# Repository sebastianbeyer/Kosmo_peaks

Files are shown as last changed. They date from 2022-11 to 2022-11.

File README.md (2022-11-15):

# Summit is a KOSMO adaption of [Matias Levy's bluepill version](https://github.com/matias-levy/peaks) of [Mutable instrument's Peaks](https://mutable-instruments.net/modules/peaks/)

> **Warning**
> You need the 128k flash version of the bluepill board which might be difficult to obtain. I was lucky with [this](https://www.amazon.com/Teyleten-Robot-Development-STM32F103C8T6-Learning/dp/B08THXZ6XK) item, someone on the LMNC forum was able to get a 128k [here on aliexpress](https://www.aliexpress.us/item/3256801435312142.html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), but there is no guarantee!

## Gerbers
Can be found in the [latest release](https://github.com/sebastianbeyer/Kosmo_peaks/releases/latest)

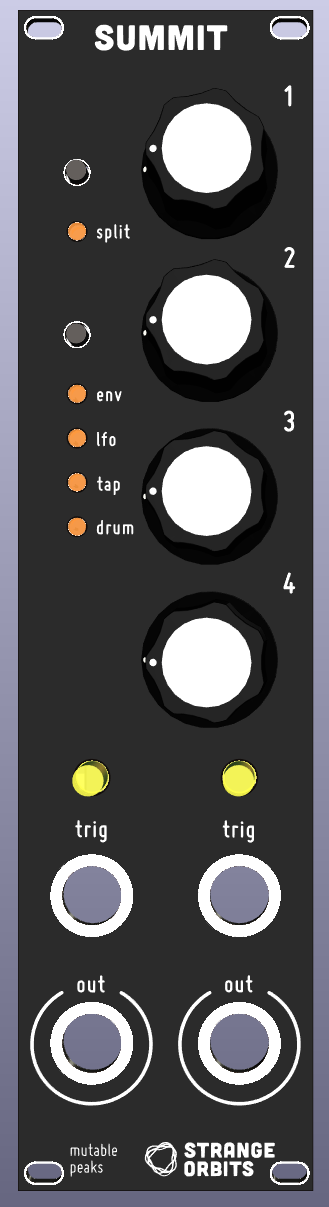
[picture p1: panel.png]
Render of the Panel


## Firmwares
There's the option to flash one of two firmwares that where ported. The original Mutable Instruments one is in the firmware/peaks directory. The [Mutated Mutables Dead Man's Catch](https://github.com/timchurches/Mutated-Mutables/tree/master/peaks) is in the firmware/peaks2. The later adds a lot of functionality to the module, although the UI becomes a bit confusing. <br>
Compiled binaries and HEX files are provided for both under firmware/build.

## Changes
* Added a driver for the PWM DAC running at **14 bit depth, 48Khz sampling rate.** (File in firmware/peaks/drivers/pwm_dac.h)
* Activated the clock for the TIM4 in firmware/peaks/drivers/system.cc
* **Bypassed the bootloader:** This was done as to simplify the code, it does not interfere with the calibration functionality of the module.
* Redesigned the output portion of the hardware to accommodate to the PWM levels.

## Flashing and development
To make it easier I have left binaries and .HEX files in firmware/build, this can be flashed directly to the bluepill using [STM32CubeProgrammer](https://www.st.com/en/development-tools/stm32cubeprog.html). <br>
Another option is to install the [mutable-dev-environment](https://github.com/pichenettes/mutable-dev-environment) and replace the peaks folder with the one inside /firmware, then executing

    make -f peaks/makefile upload_serial

We use this command because the bootloader is bypassed.

## Thanks
I want to thank Emilie Gillet for open-sourcing her work which is a constant inspiration for many musicians and makers, and encourage everyone interested in this project to checkout the [Mutable instrument's Forum](https://forum.mutable-instruments.net/) in which Emilie is a very active member.

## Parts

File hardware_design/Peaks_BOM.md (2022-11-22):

# Peaks.kicad_sch BOM

Tue 22 Nov 2022 12:02:50 CET

Generated from schematic by Eeschema 6.0.8-f2edbf62ab~116~ubuntu22.04.1

**Component Count:** 69

| Refs | Qty | Component | Description | Vendor | SKU |
| ----- | --- | ---- | --- | ---- | ---- |
| C1, C4 | 2 | 150pf | Unpolarized capacitor |  |  |
| C2, C3, C5, C6 | 4 | 4.7n | Unpolarized capacitor |  |  |
| C7, C8, C9, C12 | 4 | 100n | Unpolarized capacitor |  |  |
| C10, C13 | 2 | 10u |  |  |  |
| C11 | 1 | 0.33u |  |  |  |
| D1 | 1 | 3.6 | Zener diode |  |  |
| D2, D3, D4, D5, D6 | 5 | LED | 3 mm Light emitting diode |  |  |
| D7, D8 | 2 | 1N5817 | 20V 1A Schottky Barrier Rectifier Diode, DO-41 |  |  |
| J1 | 1 | out1 | Audio Jack, 2 Poles (Mono / TS), Switched T Pole (Normalling) |  |  |
| J2 | 1 | out2 | Audio Jack, 2 Poles (Mono / TS), Switched T Pole (Normalling) |  |  |
| J3 | 1 | Conn_01x06_Male | Generic connector, single row, 01x06, script generated (kicad-library-utils/schlib/autogen/connector/) |  |  |
| J4 | 1 | Conn_01x06_Female | Generic connector, single row, 01x06, script generated (kicad-library-utils/schlib/autogen/connector/) |  |  |
| J5 | 1 | in1 | Audio Jack, 2 Poles (Mono / TS), Switched T Pole (Normalling) |  |  |
| J6 | 1 | in2 | Audio Jack, 2 Poles (Mono / TS), Switched T Pole (Normalling) |  |  |
| J7 | 1 | Synth_power_2x5 | Pin header 2.54 mm 2x5 | Tayda | A-2939 |
| Q1, Q2 | 2 | 2N3904 | 0.2A Ic, 40V Vce, Small Signal NPN Transistor, TO-92 |  |  |
| R1, R9 | 2 | 33k | Resistor |  |  |
| R2, R6, R10, R14 | 4 | 1k5 | Resistor |  |  |
| R3, R11 | 2 | 15k | Resistor |  |  |
| R4, R12 | 2 | 180k | Resistor |  |  |
| R5, R13 | 2 | 12k | Resistor |  |  |
| R7, R15 | 2 | 6k8 | Resistor |  |  |
| R8, R16 | 2 | 1k | Resistor |  |  |
| R17 | 1 | 10k | Resistor |  |  |
| R18, R27 | 2 | 10k | Resistor |  |  |
| R19, R20, R21, R22, R23, R24, R25 | 7 | LED | Resistor |  |  |
| R26, R28 | 2 | 100k | Resistor |  |  |
| RV1, RV2, RV3, RV4 | 4 | B10k |  |  |  |
| SW3 | 1 | TRIG_LED1 |  |  | HIGHLY_PB6149L |
| SW4 | 1 | TRIG2_LED |  |  | HIGHLY_PB6149L |
| SW5, SW6 | 2 | SW_Push | Push button switch, generic, two pins |  |  |
| U1 | 1 | TL074 | Quad Low-Noise JFET-Input Operational Amplifiers, DIP-14/SOIC-14 |  |  |
| U2 | 1 | Bluepill |  |  |  |
| U3 | 1 | 78l05 | Positive 100mA 30V Linear Regulator, Fixed Output 5V, TO-92 |  |  |

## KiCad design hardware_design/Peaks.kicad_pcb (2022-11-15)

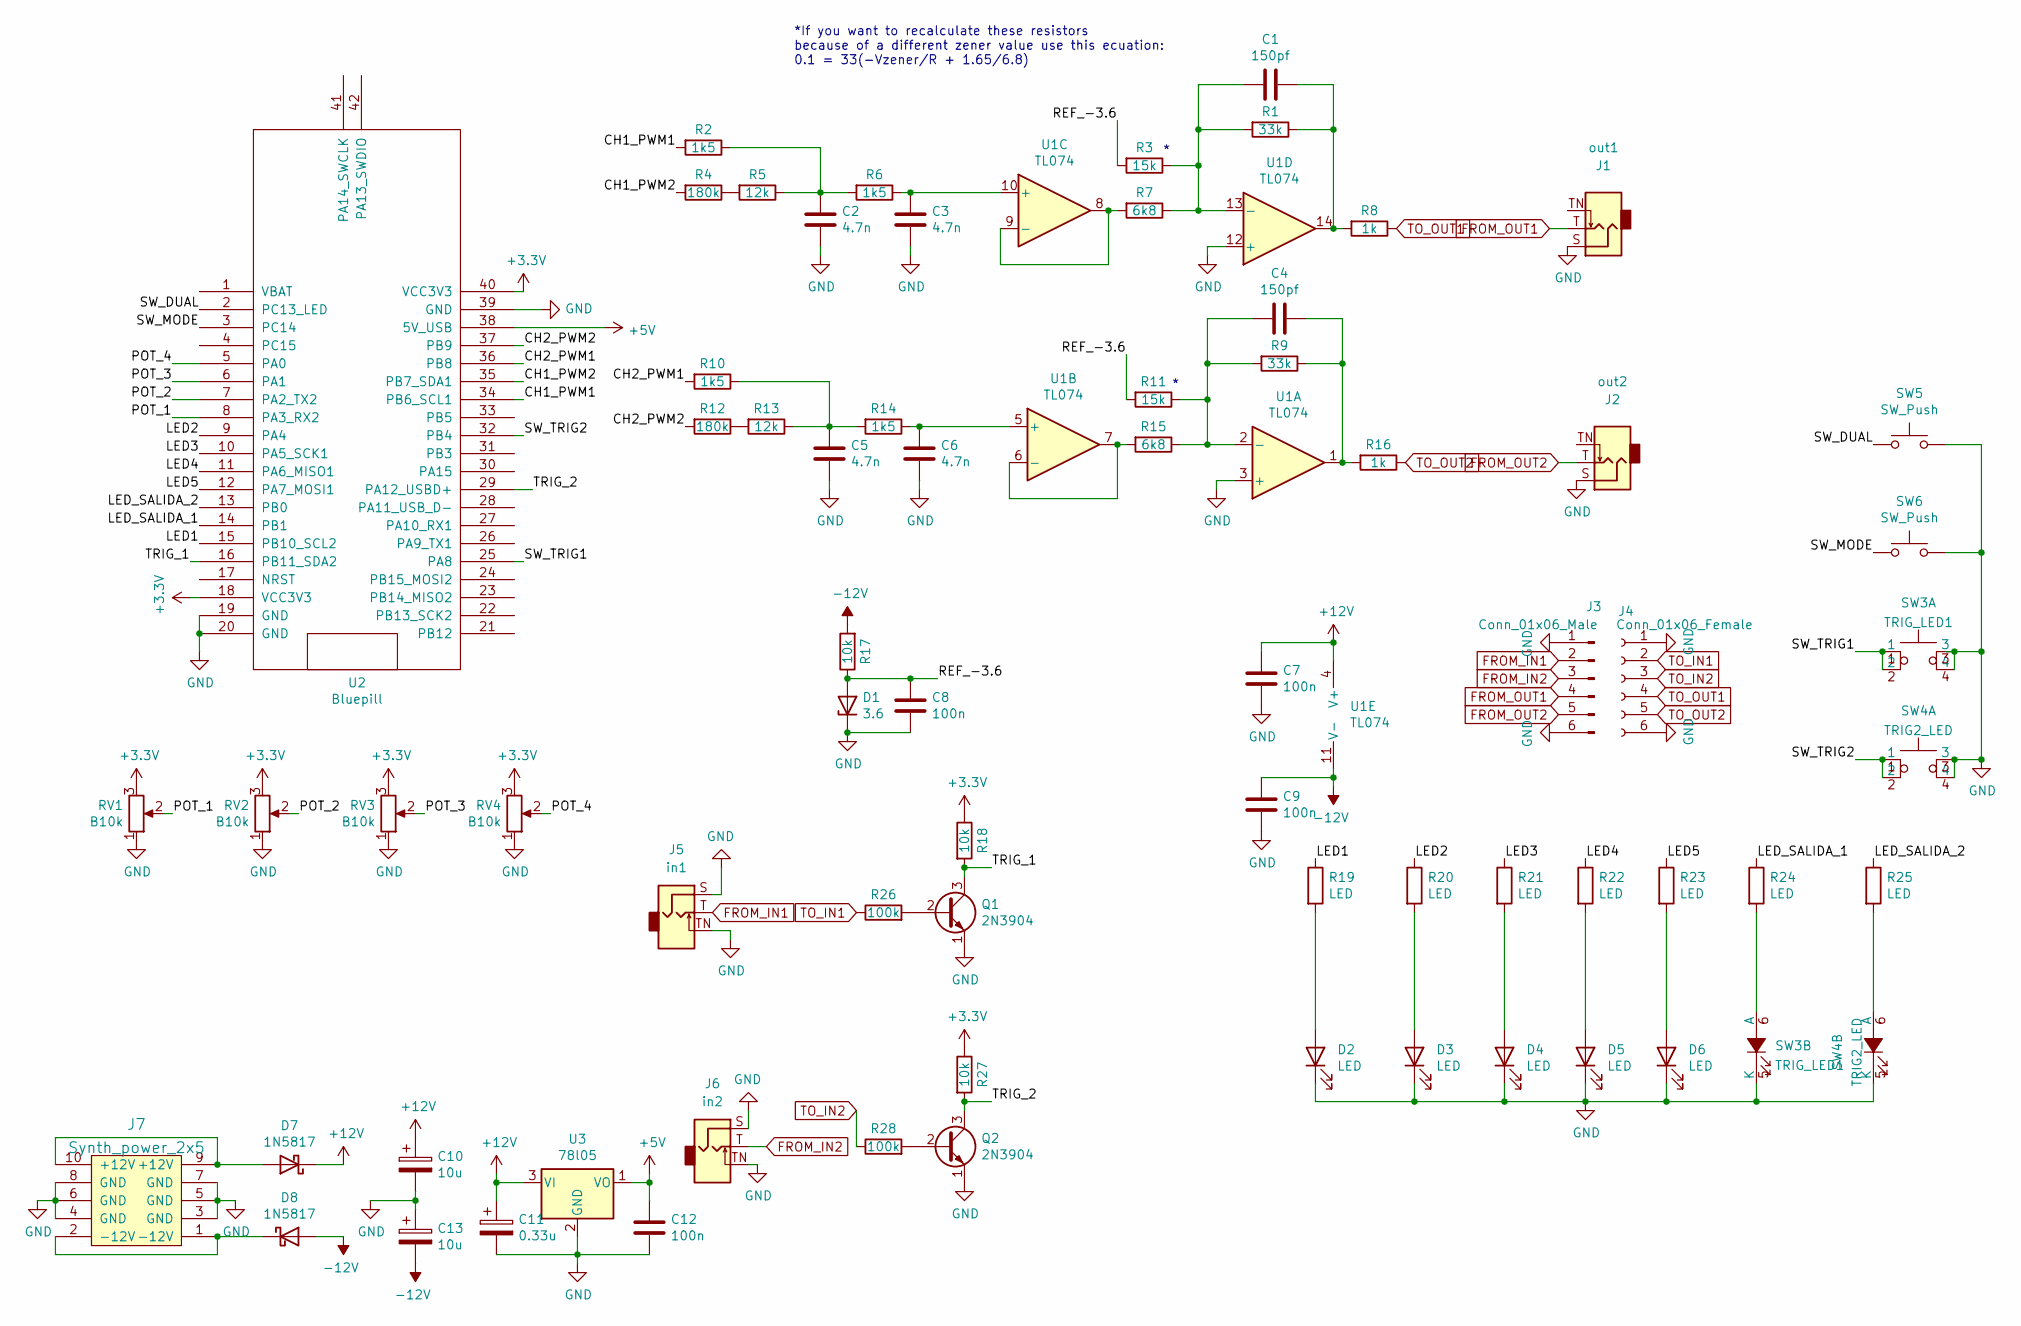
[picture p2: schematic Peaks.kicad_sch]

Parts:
C1, C4: 150pf; C_Disc_D3.0mm_W1.6mm_P2.50mm
C2, C3, C5, C6: 4.7n; C_Disc_D3.0mm_W1.6mm_P2.50mm
C7, C8, C9, C12: 100n; C_Disc_D3.0mm_W1.6mm_P2.50mm
C10, C13: 10u; CP_Radial_horizontalflat_D5mm_P2.50mm_H10mm_south
C11: 0.33u; CP_Radial_horizontalflat_D5mm_P2.50mm_H10mm_south
D1: 3.6; D_DO-35_SOD27_P7.62mm_Horizontal
D2, D3, D4, D5, D6: LED; LED_D3.0mm_FlatTop
D7, D8: 1N5817; D_DO-41_SOD81_P10.16mm_Horizontal
J1: out1; Jack_6.35mm_PJ_629HAN_slots
J2: out2; Jack_6.35mm_PJ_629HAN_slots
J3: Conn_01x06_Male; PinHeader_1x06_P2.54mm_Vertical
J4: Conn_01x06_Female; PinSocket_1x06_P2.54mm_Vertical
J5: in1; Jack_6.35mm_PJ_629HAN_slots
J6: in2; Jack_6.35mm_PJ_629HAN_slots
J7: Synth_power_2x5; Power_Header
Q1, Q2: 2N3904; TO-92_Inline_Wide
R1, R9: 33k; R_Axial_DIN0207_L6.3mm_D2.5mm_P10.16mm_Horizontal
R2, R6, R10, R14: 1k5; R_Axial_DIN0207_L6.3mm_D2.5mm_P10.16mm_Horizontal
R3, R11: 15k; R_Axial_DIN0207_L6.3mm_D2.5mm_P10.16mm_Horizontal
R4, R12: 180k; R_Axial_DIN0207_L6.3mm_D2.5mm_P10.16mm_Horizontal
R5, R13: 12k; R_Axial_DIN0207_L6.3mm_D2.5mm_P10.16mm_Horizontal
R7, R15: 6k8; R_Axial_DIN0207_L6.3mm_D2.5mm_P10.16mm_Horizontal
R8, R16: 1k; R_Axial_DIN0207_L6.3mm_D2.5mm_P10.16mm_Horizontal
R17: 10k; R_Axial_DIN0207_L6.3mm_D2.5mm_P10.16mm_Horizontal
R18, R27: 10k; R_Axial_DIN0207_L6.3mm_D2.5mm_P2.54mm_Vertical
R19, R20, R21, R22, R23, R24, R25: LED; R_Axial_DIN0207_L6.3mm_D2.5mm_P2.54mm_Vertical
R26, R28: 100k; R_Axial_DIN0207_L6.3mm_D2.5mm_P2.54mm_Vertical
RV1, RV2, RV3, RV4: B10k; Potentiometer_Alpha_RD901F-40-00D_Single_Vertical_centered
SW3: TRIG_LED1; HIGHLY_PB6149L
SW4: TRIG2_LED; HIGHLY_PB6149L
SW5, SW6: SW_Push; SW_PUSH_6mm_H13mm
U1: TL074; DIP-14_W7.62mm_Socket_LongPads
U2: Bluepill; BluePill_STM32F103C
U3: 78l05; TO-220-3_Horizontal_TabDown

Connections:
+3V3: R18.1, R27.1, RV1.3, RV2.3, RV3.3, RV4.3, U2.18 (VCC3V3), U2.40 (VCC3V3)
+5V: C12.1, U2.38 (5V_USB), U3.1 (VO)
+12V: C7.1, C10.1, C11.1, D7.1 (K), U1.4 (V+), U3.3 (VI)
-12V: C9.1, C13.2, D8.2 (A), R17.2, U1.11 (V-)
/CH1_PWM1: R2.2, U2.34 (PB6_SCL1)
/CH1_PWM2: R4.2, U2.35 (PB7_SDA1)
/CH2_PWM1: R10.2, U2.36 (PB8)
/CH2_PWM2: R12.2, U2.37 (PB9)
/LED1: R19.1, U2.15 (PB10_SCL2)
/LED2: R20.1, U2.9 (PA4)
/LED3: R21.1, U2.10 (PA5_SCK1)
/LED4: R22.1, U2.11 (PA6_MISO1)
/LED5: R23.1, U2.12 (PA7_MOSI1)
/LED_SALIDA_1: R24.1, U2.14 (PB1)
/LED_SALIDA_2: R25.1, U2.13 (PB0)
/POT_1: RV1.2, U2.8 (PA3_RX2)
/POT_2: RV2.2, U2.7 (PA2_TX2)
/POT_3: RV3.2, U2.6 (PA1)
/POT_4: RV4.2, U2.5 (PA0)
/REF_-3.6: C8.1, D1.2 (A), R3.2, R11.2, R17.1
/SW_DUAL: SW5.1, U2.2 (PC13_LED)
/SW_MODE: SW6.1, U2.3 (PC14)
/SW_TRIG1: SW3.1, SW3.2, U2.25 (PA8)
/SW_TRIG2: SW4.1, SW4.2, U2.32 (PB4)
/TRIG_1: Q1.3 (C), R18.2, U2.16 (PB11_SDA2)
/TRIG_2: Q2.3 (C), R27.2, U2.29 (PA12_USBD+)
FROM_IN1: J3.2, J5.T
FROM_IN2: J3.3, J6.T
FROM_OUT1: J1.T, J3.4
FROM_OUT2: J2.T, J3.5
GND: C2.2, C3.2, C5.2, C6.2, C7.2, C8.2, C9.2, C10.2, C11.2, C12.2, C13.1, D1.1 (K), D2.1 (K), D3.1 (K), D4.1 (K), D5.1 (K), D6.1 (K), J1.S, J2.S, J3.1, J3.6, J4.1, J4.6, J5.S, J5.TN, J6.S, J6.TN, J7.3 (GND), J7.4 (GND), J7.5 (GND), J7.6 (GND), J7.7 (GND), J7.8 (GND), Q1.1 (E), Q2.1 (E), RV1.1, RV2.1, RV3.1, RV4.1, SW3.3, SW3.4, SW3.5 (K), SW4.3, SW4.4, SW4.5 (K), SW5.2, SW6.2, U1.3 (+), U1.12 (+), U2.19 (GND), U2.20 (GND), U2.39 (GND), U3.2 (GND)
unnamed: C1.1, R1.2, R3.1, R7.1, U1.13 (-)
unnamed: C1.2, R1.1, R8.2, U1.14
unnamed: C2.1, R2.1, R5.1, R6.2
unnamed: C3.1, R6.1, U1.10 (+)
unnamed: C4.1, R9.2, R11.1, R15.1, U1.2 (-)
unnamed: C4.2, R9.1, R16.2, U1.1
unnamed: C5.1, R10.1, R13.1, R14.2
unnamed: C6.1, R14.1, U1.5 (+)
unnamed: D2.2 (A), R19.2
unnamed: D3.2 (A), R20.2
unnamed: D4.2 (A), R21.2
unnamed: D5.2 (A), R22.2
unnamed: D6.2 (A), R23.2
unnamed: D7.2 (A), J7.9 (+12V), J7.10 (+12V)
unnamed: D8.1 (K), J7.1 (-12V), J7.2 (-12V)
unnamed: Q1.2 (B), R26.2
unnamed: Q2.2 (B), R28.2
unnamed: R4.1, R5.2
unnamed: R7.2, U1.8, U1.9 (-)
unnamed: R12.1, R13.2
unnamed: R15.2, U1.6 (-), U1.7
unnamed: R24.2, SW3.6 (A)
unnamed: R25.2, SW4.6 (A)
TO_IN1: J4.2, R26.1
TO_IN2: J4.3, R28.1
TO_OUT1: J4.4, R8.1
TO_OUT2: J4.5, R16.1

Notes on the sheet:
*If you want to recalculate these resistors because of a different zener value use this ecuation: 0.1 = 33(-Vzener/R + 1.65/6.8)

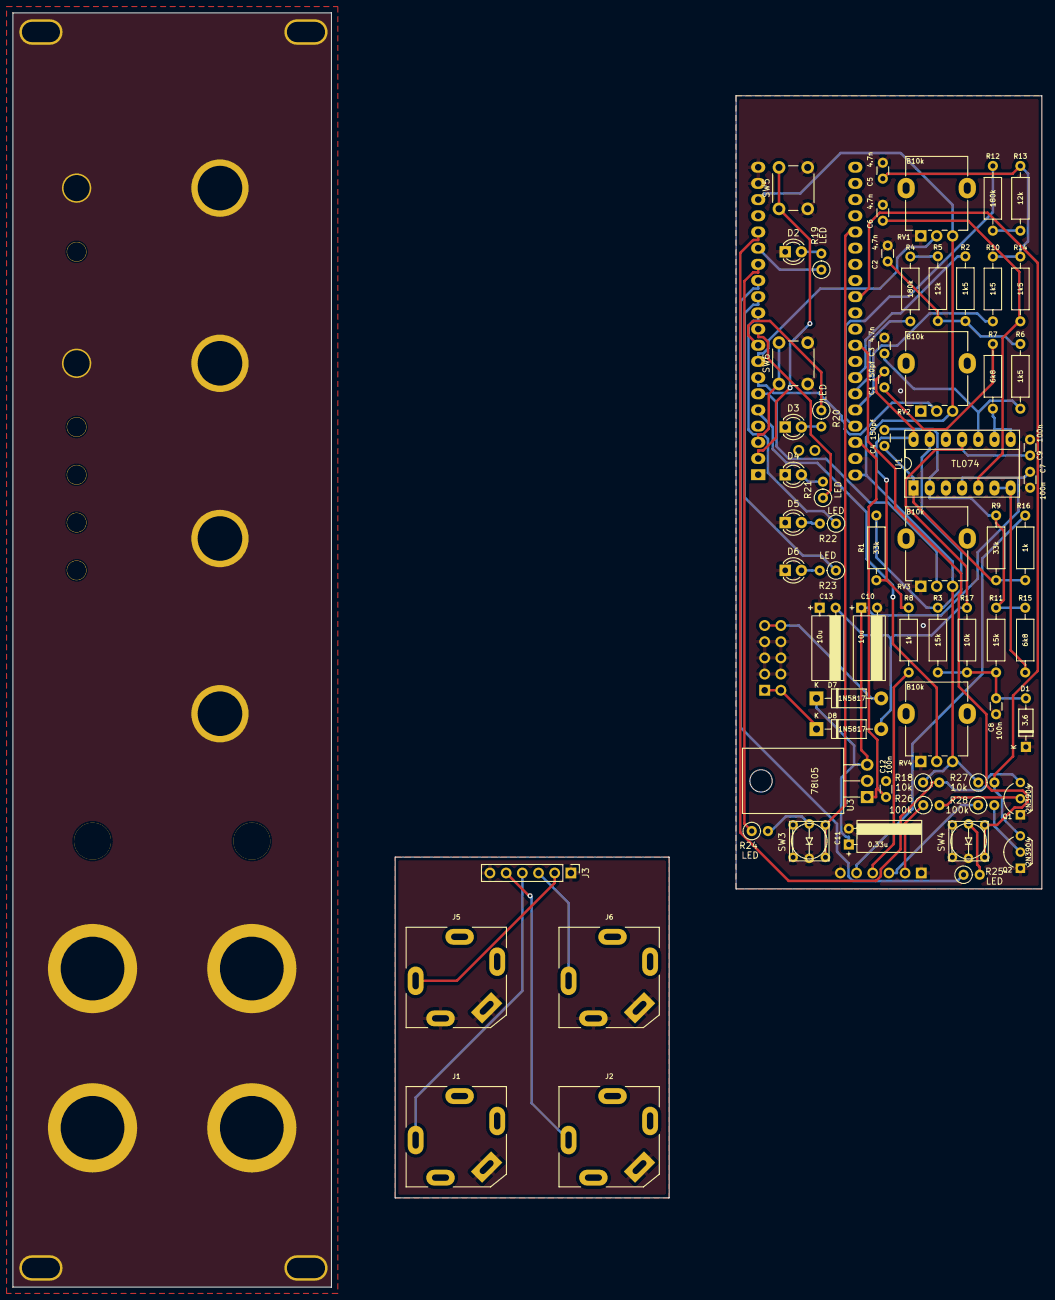
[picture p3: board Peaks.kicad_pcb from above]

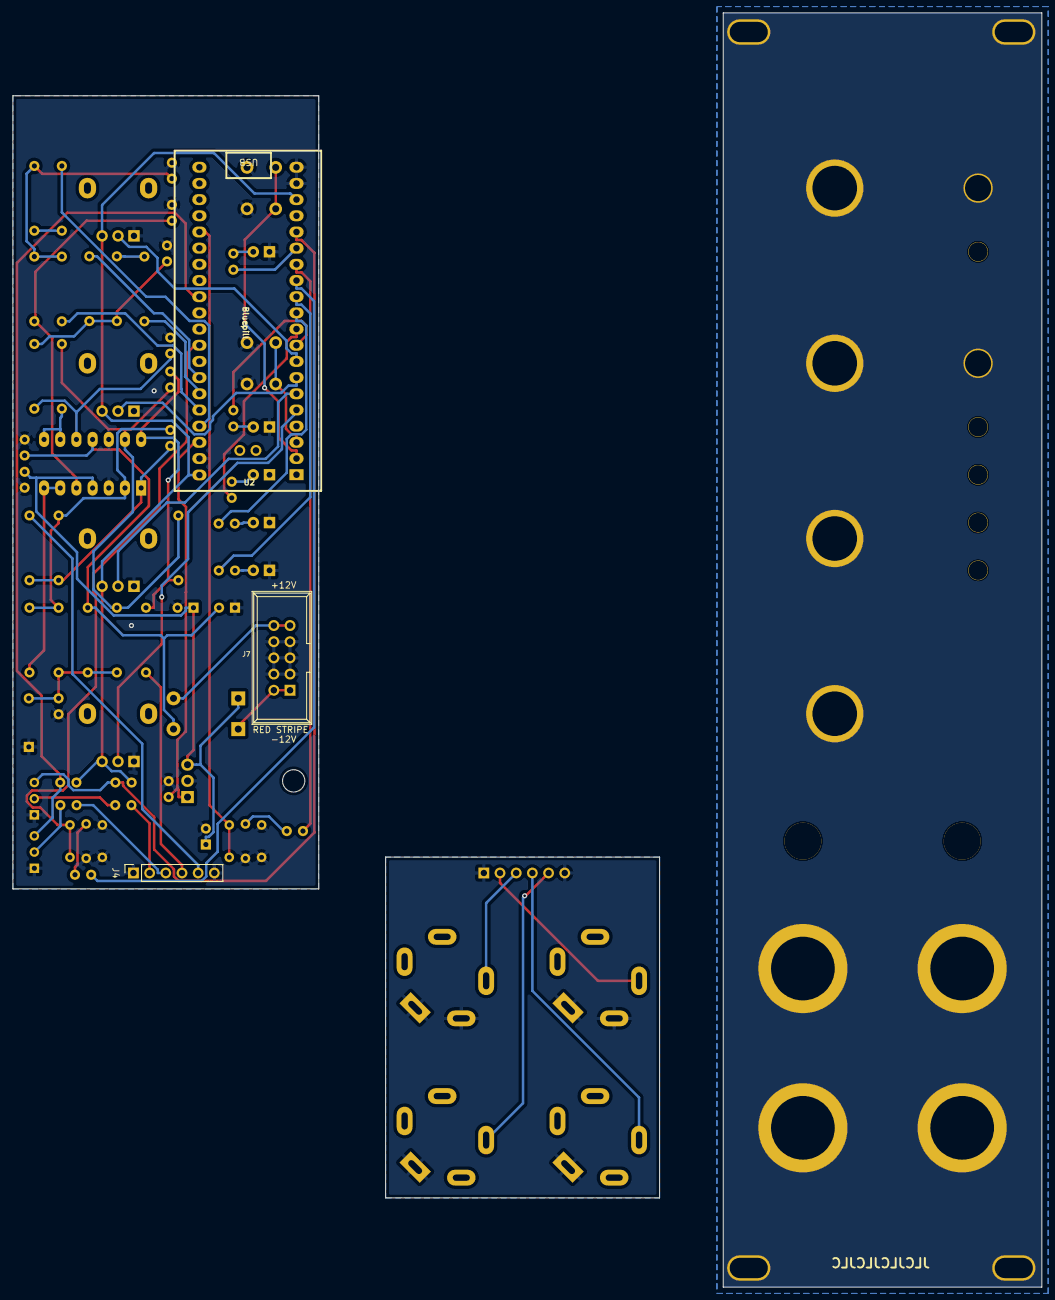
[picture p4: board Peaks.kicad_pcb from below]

Board: 2 copper layers, 161.5 x 200.0 mm, 71 parts (3 on the bottom side), 58 nets.

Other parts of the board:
H25, H25#2: led; Kosmo_HIGHLY_PB6149L

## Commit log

2022-11-15 update my KOSMO adaption
    [Peaks.kicad_pcb, Peaks.kicad_sch]
2022-11-22 add bom
